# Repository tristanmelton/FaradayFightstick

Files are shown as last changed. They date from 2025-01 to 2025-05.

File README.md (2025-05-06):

### FaradayFightstick
Utilize Hall Effect sensors in an open-source leverless.

Use an ATMEGA microcontroller to read the analog out from the hall effect sensor located on the opposite side of the PCB from the switch. Then, the ATMEGA will act as the switch and output high or low to a Brooks board for each button press.

There are board versions for a RP2040, Brooks P5 Mini and Brooks Gen-5X Mini. I have tested the RP2040 and P5 Mini versions and they both work on PC.
## Setup
The board is relatively simple to set up - the most difficult part was soldering the USB-C for the ATMEGA32u4. I have no reflow oven so I used my conventional oven with solder paste, which works but is a little difficult to get the timing right to not melt the plastic in the connector.

Once all components are soldered, burn the Arduino bootloader with the "Arduino as ISP" option with an Arduino Uno or equivalent, or another bootloader burner, connected to the ICSP headers on the ATMEGA32u4 which are broken out for convenience, set to an Arduino Micro as the target. Then, plug in the USB-C and upload the ADC.ino sketch.

Once uploaded, unplug and hold LP while plugging back in and run the configurator python script (to be wrapped into an exe later). It should automatically detect the controller. If not, select the COM port corresponding to your board (should say COMXX: Arduino Micro), and click Connect. The progress bar will fill as the default values are read from memory. Set the values using the sliders and click "Submit New Thresholds". Wait for the progress bar to fill and then you can unplug.

Unplug from the ATMEGA side and plug the controller into your computer. If using the RP2040 board, upload the GP2040-CE firmware. Once done, you should be good to go!

There is compatibility for a MagicBoots with the RP2040 board but I have not tested it nor the P5 mini or Gen-5X versions as I don't own a PS5. Always open to donations :)
## TODO
- [ ] Test the P5 Mini version on a PS5.
- [x] Add an "unpressed" level so users have an idea of what range of value to put in
- [x] Add a diode on the voltage input from each USB socket to prevent backflow of current to the host PC and damaging it

## Changelog
# v1.1 (5/5/2025)
- Added boards for P5 mini and Gen-5X mini
- Added current-blocking diodes to prevent blowing up your USB if plugged into both USB ports at the same time
- Updated ADC firmware to support additional commands:
  - GETALLVAL;: get all current button values.
  - GETALLTRIG;: get all trigger threshold levels.
  - GETTRIG;XX: get a singular trigger threshold from memory.  XX indicates the memory offset to read from.
  - LP;X, MP;X, HP;X, SHP;X,...: Sets the trigger threshold value to X in absolute units.
- Updated interface software to use sliders from 100 to 0 to set the sensitivity. 100 is max sensitivity, 0 is no sensitivity.
- Software will try and auto-detect the controller when plugged in. 
# v1.0 (3/6/2025)
The leverless is working! I wrote a quick interface with Python to read and write button trigger thresholds to the EEPROM. The system works as an official "1.0"!

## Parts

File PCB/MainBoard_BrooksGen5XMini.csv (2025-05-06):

Reference | Value | Datasheet | Footprint | Qty | DNP
C1,C3,C4,C5,C6,C9,C19,C33 | 0.1u | ~ | Capacitor_SMD:C_0603_1608Metric | 8
C2,C11,C12,C20,C34 | 1u | ~ | Capacitor_SMD:C_0603_1608Metric | 5
C7 | 4.7u | ~ | Capacitor_SMD:C_0603_1608Metric | 1
C8,C10 | 22p | ~ | Capacitor_SMD:C_0603_1608Metric | 2
C14,C15,C16,C17,C18,C24,C25,C26,C30,C31,C32,C37,C38,C39,C40,C41 | 1n | ~ | Capacitor_SMD:C_0603_1608Metric | 16
D1 | LED_GREEN | ~ | LED_SMD:LED_0201_0603Metric | 1
D2 | LED_RED | ~ | LED_SMD:LED_0201_0603Metric | 1
D3,D4,D5,D6 | D | ~ |  | 4
J1,J3 | USB4105-GF-A |  | USB4105_GF_A:GCT_USB4105-GF-A | 2
J2 | Conn_01x06_Pin | ~ | Connector_PinHeader_2.54mm:PinHeader_2x03_P2.54mm_Vertical | 1
R1,R9,R10,R15 | 5.1k | ~ | Resistor_SMD:R_0603_1608Metric | 4
R2,R3,R8,R11,R12,R13,R14,R18,R19,R20,R24,R25,R26,R29,R30,R31,R32,R33 | 22 | ~ | Resistor_SMD:R_0603_1608Metric | 18
R4,R5 | 1k | ~ | Resistor_SMD:R_0603_1608Metric | 2
R6,R7 | 10k | ~ | Resistor_SMD:R_0603_1608Metric | 2
R27,R34 | 51 | ~ | Resistor_SMD:R_0603_1608Metric | 2
SW_RESET1 | SW_Push | ~ | Button_Switch_SMD:SW_SPST_TL3342 | 1
U1,U3 | ADC108S022CIMTX/NOPB | ADC108S022CIMTX/NOPB | ADCs:MTC16 | 2
U2,U21,U22,U23,U24,U25,U26,U27,U28,U29,U30,U31,U32,U33,U34,U35,U36,U37 | ~ |  | -- mixed values -- | 18
U4,U5,U6,U7,U8,U9,U10,U11,U12,U13,U14,U15,U16,U17,U18,U19 | DRV5053VAQDBZR | DRV5053VAQDBZR | HallEffect:DBZ0003A_N | 16
U20 | ATmega32U4-A | http://ww1.microchip.com/downloads/en/DeviceDoc/Atmel-7766-8-bit-AVR-ATmega16U4-32U4_Datasheet.pdf | Package_QFP:TQFP-44_10x10mm_P0.8mm | 1
Y2 | Crystal_GND24 | ~ | Crystal:Crystal_SMD_SeikoEpson_FA238-4Pin_3.2x2.5mm | 1

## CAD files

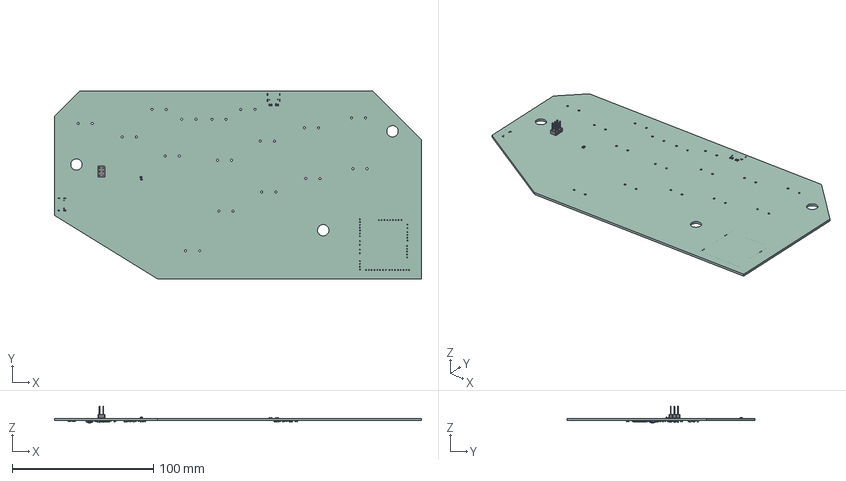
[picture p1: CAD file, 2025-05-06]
PCB/MainBoard_BrooksP5Mini.step
259.5 x 133.0 x 11.8 mm
PinHeader_2x03_P254mm_Vertical
D_0603 x 4
R_0603_1608Metric x 27
C_0603_1608Metric x 32
TQFP_44_10x10mm_P08mm
SW_SPST_TL3342
Crystal_SMD_SeikoEpson_FA238-4Pin_3.2x2.5mm
LED_0201_0603Metric
MainBoard_BrooksP5Mini_PCB

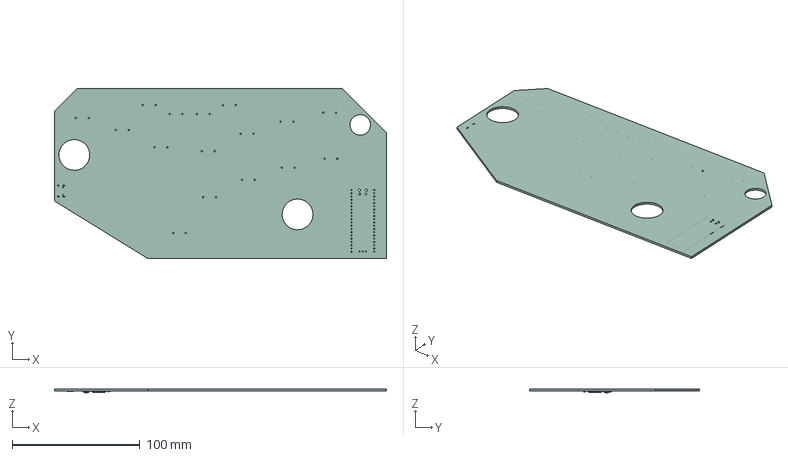
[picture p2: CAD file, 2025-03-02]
PCB/MainBoard_RP2040.step
259.5 x 133.0 x 3.19 mm
TQFP_44_10x10mm_P08mm
C_0603_1608Metric x 8
R_0603_1608Metric x 7
SW_SPST_TL3342
Crystal_SMD_SeikoEpson_FA238-4Pin_3.2x2.5mm
LED_0201_0603Metric
_autosave-MainBoard_RP2040_PCB

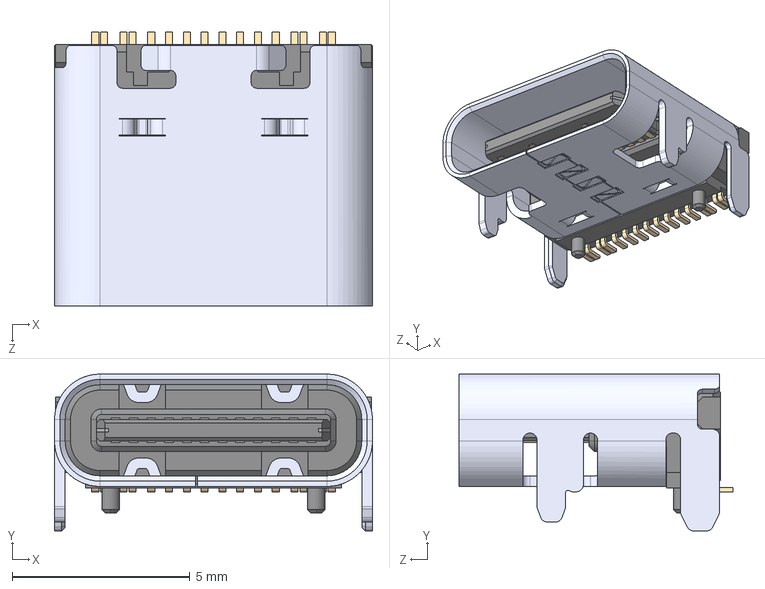
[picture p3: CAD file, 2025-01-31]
Components/USB4105_GF_A/USB4105-GF-A.step
8.94 x 4.41 x 7.71 mm

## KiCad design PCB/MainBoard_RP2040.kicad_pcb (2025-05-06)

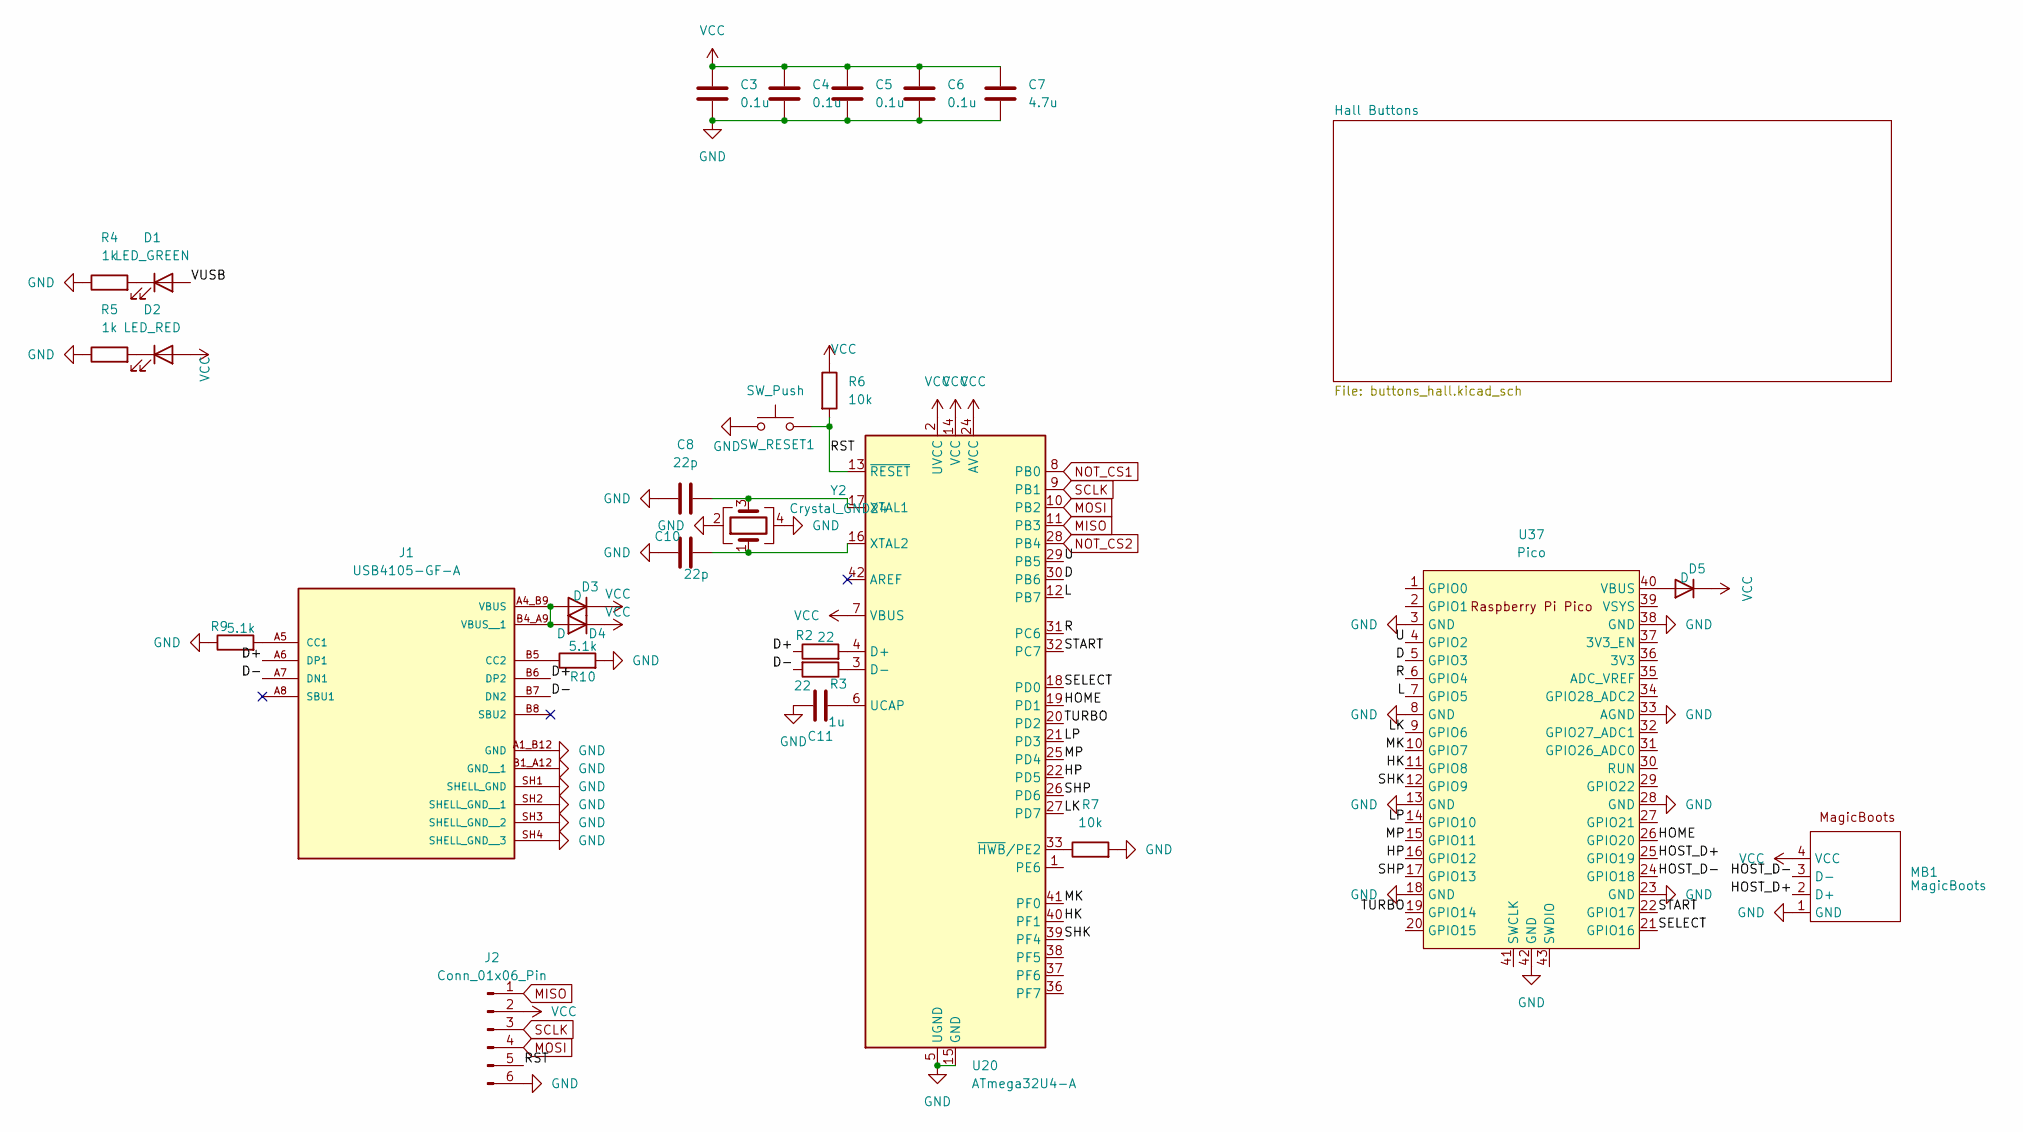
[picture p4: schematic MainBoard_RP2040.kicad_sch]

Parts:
C3, C4, C5, C6: 0.1u; C_0603_1608Metric
C7: 4.7u; C_0603_1608Metric
C8, C10: 22p; C_0603_1608Metric
C11: 1u; C_0603_1608Metric
D1: LED_GREEN; LED_0201_0603Metric
D2: LED_RED; LED_0201_0603Metric
D3, D4, D5: D; D_0603_1608Metric
J1: USB4105-GF-A; GCT_USB4105-GF-A; PARTREV B4
J2: Conn_01x06_Pin; PinHeader_2x03_P2.54mm_Vertical
MB1: MagicBoots
R2, R3: 22; R_0603_1608Metric
R4, R5: 1k; R_0603_1608Metric
R6, R7: 10k; R_0603_1608Metric
R9, R10: 5.1k; R_0603_1608Metric
SW_RESET1: SW_Push; SW_SPST_TL3342
U20: ATmega32U4-A; TQFP-44_10x10mm_P0.8mm
U37: Pico; RPi_Pico_SMD_TH
Y2: Crystal_GND24; Crystal_SMD_SeikoEpson_FA238-4Pin_3.2x2.5mm

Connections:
/D: U20.30 (PB6), U37.5 (GPIO3)
/D+: J1.A6 (DP1), J1.B6 (DP2), R2.1
/D-: J1.A7 (DN1), J1.B7 (DN2), R3.2
/HK: U20.40 (PF1), U37.11 (GPIO8)
/HOME: U20.19 (PD1), U37.26 (GPIO20)
/HOST_D+: MB1.2 (D+), U37.25 (GPIO19)
/HOST_D-: MB1.3 (D-), U37.24 (GPIO18)
/HP: U20.22 (PD5), U37.16 (GPIO12)
/L: U20.12 (PB7), U37.7 (GPIO5)
/LK: U20.27 (PD7), U37.9 (GPIO6)
/LP: U20.21 (PD3), U37.14 (GPIO10)
/MK: U20.41 (PF0), U37.10 (GPIO7)
/MP: U20.25 (PD4), U37.15 (GPIO11)
/R: U20.31 (PC6), U37.6 (GPIO4)
/RST: J2.5, R6.2, SW_RESET1.2, U20.13 (~RESET)
/SELECT: U20.18 (PD0), U37.21 (GPIO16)
/SHK: U20.39 (PF4), U37.12 (GPIO9)
/SHP: U20.26 (PD6), U37.17 (GPIO13)
/START: U20.32 (PC7), U37.22 (GPIO17)
/TURBO: U20.20 (PD2), U37.19 (GPIO14)
/U: U20.29 (PB5), U37.4 (GPIO2)
GND: C3.2, C4.2, C5.2, C6.2, C7.2, C8.1, C10.1, C11.1, J1.A1_B12 (GND), J1.B1_A12 (GND__1), J1.SH1 (SHELL_GND), J1.SH2 (SHELL_GND__1), J1.SH3 (SHELL_GND__2), J1.SH4 (SHELL_GND__3), J2.6, MB1.1 (GND), R4.1, R5.1, R7.2, R9.1, R10.2, SW_RESET1.1, U20.5 (UGND), U20.15 (GND), U20.23 (GND), U20.35 (GND), U20.43 (GND), U37.3 (GND), U37.8 (GND), U37.13 (GND), U37.18 (GND), U37.23 (GND), U37.28 (GND), U37.33 (AGND), U37.38 (GND), U37.42 (GND), Y2.2, Y2.4; also elsewhere on the board
MISO: J2.1, U20.11 (PB3); also elsewhere on the board
MOSI: J2.4, U20.10 (PB2); also elsewhere on the board
NOT_CS1: U20.8 (PB0); also elsewhere on the board
NOT_CS2: U20.28 (PB4); also elsewhere on the board
unnamed: D1.1 (K), R4.2
unnamed: D2.1 (K), R5.2
unnamed: D3.2 (A), D4.2 (A), J1.A4_B9 (VBUS), J1.B4_A9 (VBUS__1)
unnamed: D5.2 (A), U37.40 (VBUS)
unnamed: J1.A5 (CC1), R9.2
unnamed: J1.B5 (CC2), R10.1
unnamed: R2.2, U20.4 (D+)
unnamed: R3.1, U20.3 (D-)
unnamed: C11.2, U20.6 (UCAP)
unnamed: C8.2, U20.17 (XTAL1), Y2.3
unnamed: C10.2, U20.16 (XTAL2), Y2.1
unnamed: R7.1, U20.33 (~HWB/PE2)
SCLK: J2.3, U20.9 (PB1); also elsewhere on the board
VCC: C3.1, C4.1, C5.1, C6.1, C7.1, D2.2 (A), D3.1 (K), D4.1 (K), D5.1 (K), J2.2, MB1.4 (VCC), R6.1, U20.2 (UVCC), U20.7 (VBUS), U20.14 (VCC), U20.24 (AVCC), U20.34 (VCC), U20.44 (AVCC); also elsewhere on the board

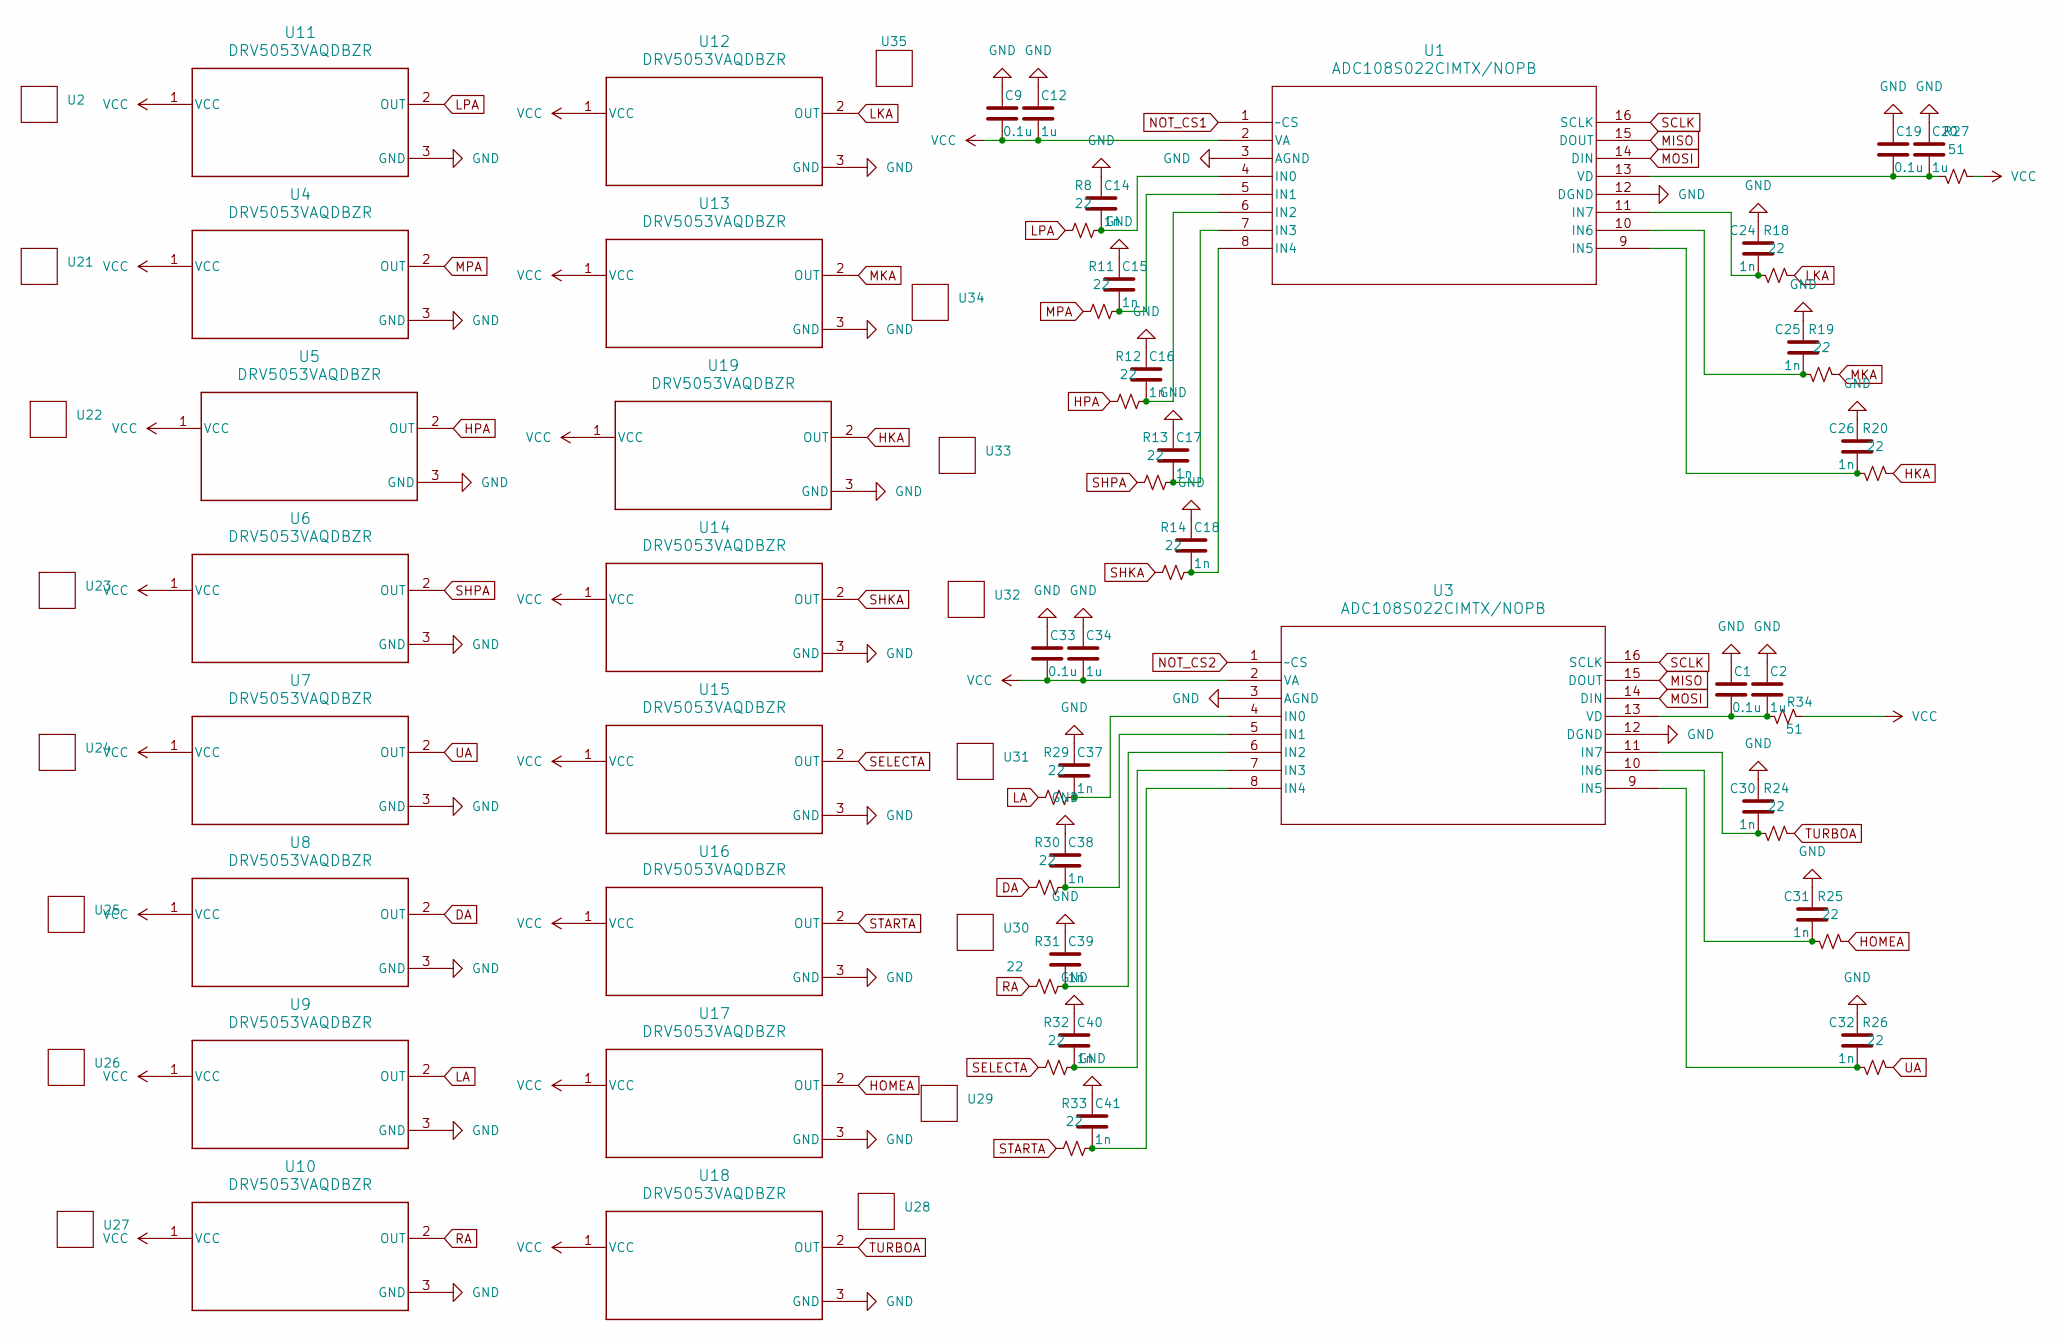
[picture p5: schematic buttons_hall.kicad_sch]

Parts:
C1, C9, C19, C33: 0.1u; C_0603_1608Metric
C2, C12, C20, C34: 1u; C_0603_1608Metric
C14, C15, C16, C17, C18, C24, C25, C26, C30, C31, C32, C37, C38, C39, C40, C41: 1n; C_0603_1608Metric
R8, R11, R12, R13, R14, R18, R19, R20, R24, R25, R26, R29, R30, R31, R32, R33: 22; R_0603_1608Metric
R27, R34: 51; R_0603_1608Metric
U1, U3: ADC108S022CIMTX/NOPB; MTC16
U2, U21, U22, U23, U24, U25, U26, U27, U28, U29, U30, U31, U32, U33, U34, U35: Gateron Jade Pro Magnetic
U4, U5, U6, U7, U8, U9, U10, U11, U12, U13, U14, U15, U16, U17, U18, U19: DRV5053VAQDBZR; DBZ0003A_N

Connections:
DA: R30.1, U8.2 (OUT)
GND: C1.1, C2.1, C9.1, C12.1, C14.1, C15.1, C16.1, C17.1, C18.1, C19.1, C20.1, C24.1, C25.1, C26.1, C30.1, C31.1, C32.1, C33.1, C34.1, C37.1, C38.1, C39.1, C40.1, C41.1, U1.3 (AGND), U1.12 (DGND), U3.3 (AGND), U3.12 (DGND), U4.3 (GND), U5.3 (GND), U6.3 (GND), U7.3 (GND), U8.3 (GND), U9.3 (GND), U10.3 (GND), U11.3 (GND), U12.3 (GND), U13.3 (GND), U14.3 (GND), U15.3 (GND), U16.3 (GND), U17.3 (GND), U18.3 (GND), U19.3 (GND); also elsewhere on the board
HKA: R20.1, U19.2 (OUT)
HOMEA: R25.1, U17.2 (OUT)
HPA: R12.1, U5.2 (OUT)
LA: R29.1, U9.2 (OUT)
LKA: R18.1, U12.2 (OUT)
LPA: R8.1, U11.2 (OUT)
MISO: U1.15 (DOUT), U3.15 (DOUT); also elsewhere on the board
MKA: R19.1, U13.2 (OUT)
MOSI: U1.14 (DIN), U3.14 (DIN); also elsewhere on the board
MPA: R11.1, U4.2 (OUT)
NOT_CS1: U1.1 (~CS); also elsewhere on the board
NOT_CS2: U3.1 (~CS); also elsewhere on the board
unnamed: C14.2, R8.2, U1.4 (IN0)
unnamed: C15.2, R11.2, U1.5 (IN1)
unnamed: C16.2, R12.2, U1.6 (IN2)
unnamed: C17.2, R13.2, U1.7 (IN3)
unnamed: C18.2, R14.2, U1.8 (IN4)
unnamed: C26.2, R20.2, U1.9 (IN5)
unnamed: C25.2, R19.2, U1.10 (IN6)
unnamed: C24.2, R18.2, U1.11 (IN7)
unnamed: C19.2, C20.2, R27.2, U1.13 (VD)
unnamed: C37.2, R29.2, U3.4 (IN0)
unnamed: C38.2, R30.2, U3.5 (IN1)
unnamed: C39.2, R31.2, U3.6 (IN2)
unnamed: C40.2, R32.2, U3.7 (IN3)
unnamed: C41.2, R33.2, U3.8 (IN4)
unnamed: C32.2, R26.2, U3.9 (IN5)
unnamed: C31.2, R25.2, U3.10 (IN6)
unnamed: C30.2, R24.2, U3.11 (IN7)
unnamed: C1.2, C2.2, R34.2, U3.13 (VD)
RA: R31.1, U10.2 (OUT)
SCLK: U1.16 (SCLK), U3.16 (SCLK); also elsewhere on the board
SELECTA: R32.1, U15.2 (OUT)
SHKA: R14.1, U14.2 (OUT)
SHPA: R13.1, U6.2 (OUT)
STARTA: R33.1, U16.2 (OUT)
TURBOA: R24.1, U18.2 (OUT)
UA: R26.1, U7.2 (OUT)
VCC: C9.2, C12.2, C33.2, C34.2, R27.1, R34.1, U1.2 (VA), U3.2 (VA), U4.1 (VCC), U5.1 (VCC), U6.1 (VCC), U7.1 (VCC), U8.1 (VCC), U9.1 (VCC), U10.1 (VCC), U11.1 (VCC), U12.1 (VCC), U13.1 (VCC), U14.1 (VCC), U15.1 (VCC), U16.1 (VCC), U17.1 (VCC), U18.1 (VCC), U19.1 (VCC); also elsewhere on the board

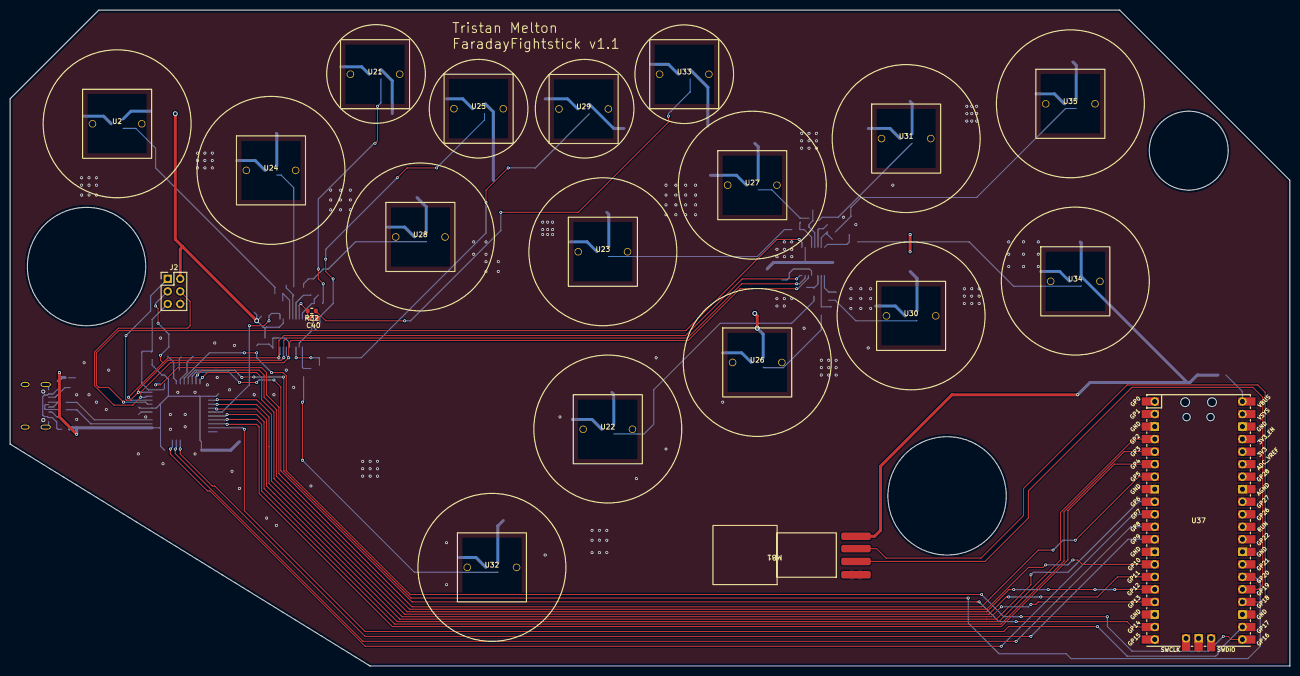
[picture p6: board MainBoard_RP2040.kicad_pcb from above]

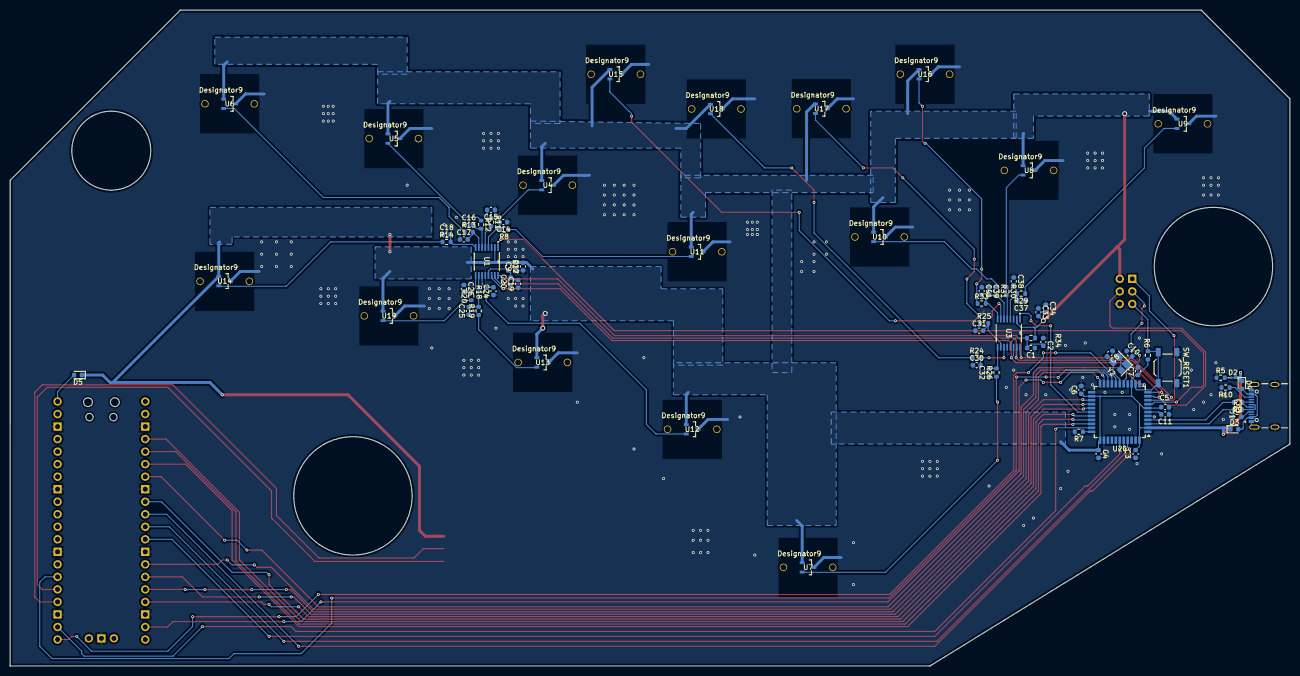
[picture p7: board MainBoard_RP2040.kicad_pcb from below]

Board: 2 copper layers, 259.5 x 133.0 mm, 102 parts (81 on the bottom side), 73 nets.

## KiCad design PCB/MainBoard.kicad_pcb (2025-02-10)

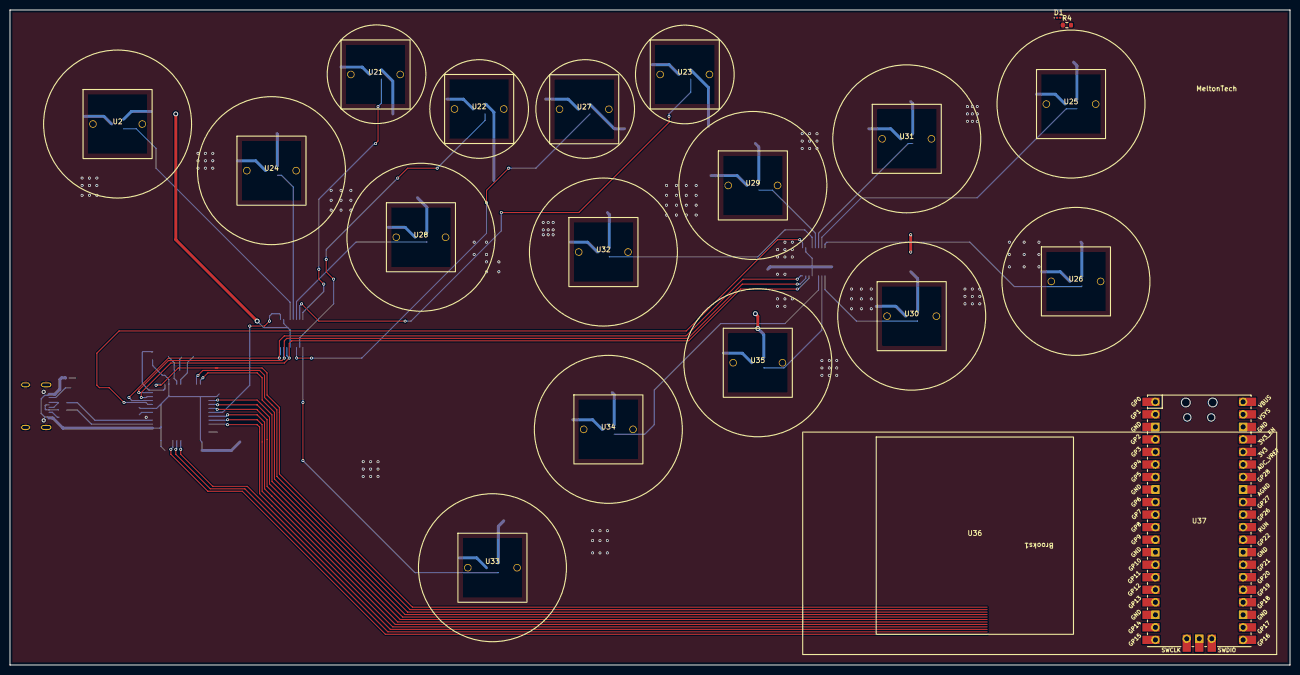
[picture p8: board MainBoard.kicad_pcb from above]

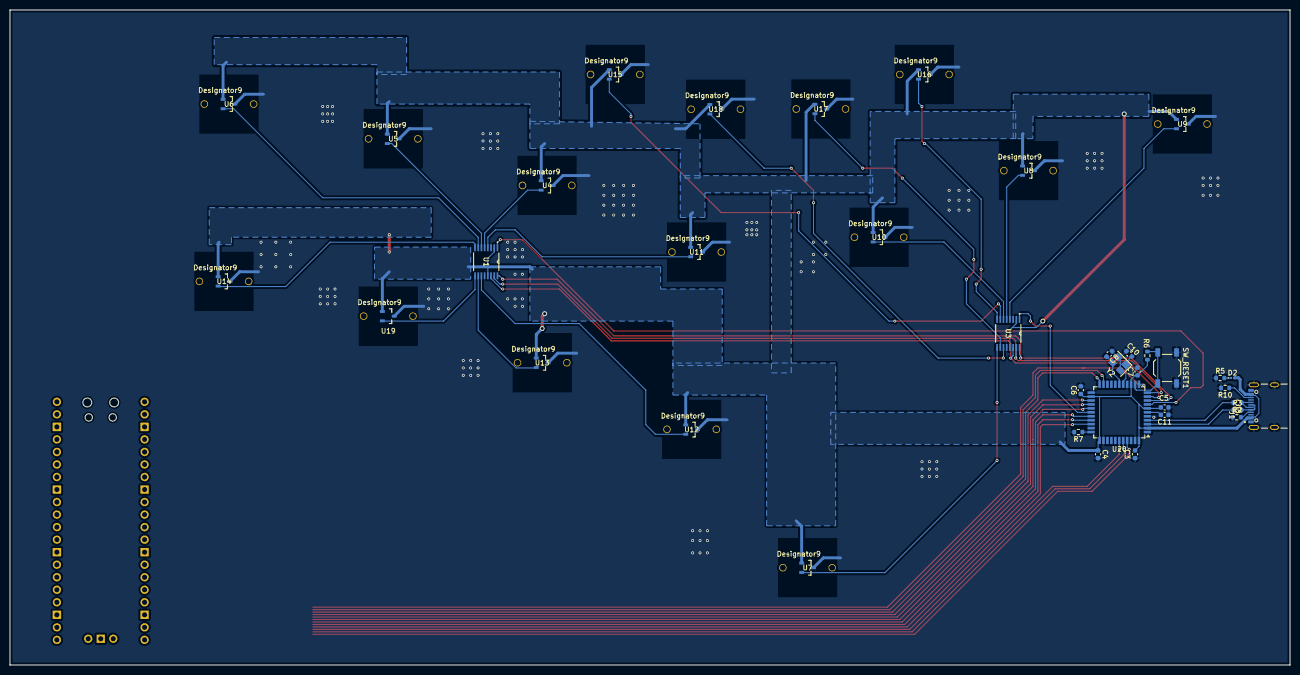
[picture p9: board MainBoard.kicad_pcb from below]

Board: 2 copper layers, 259.5 x 132.8 mm, 59 parts (38 on the bottom side), 36 nets.

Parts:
Brooks1: BrooksP5Plus
C3, C4, C5, C6: 0.1u; C_0603_1608Metric
C7: 4.7u; C_0603_1608Metric
C8, C10: 22p; C_0603_1608Metric
C11: 1u; C_0603_1608Metric
D1: LED_GREEN; LED_0201_0603Metric
D2: LED_RED; LED_0201_0603Metric
J1: USB4105-GF-A; GCT_USB4105-GF-A
R2, R3: 22; R_0603_1608Metric
R4, R5: 1k; R_0603_1608Metric
R6, R7: 10k; R_0603_1608Metric
R9, R10: 5.1k; R_0603_1608Metric
SW_RESET1: SW_Push; SW_SPST_TL3342
U1, U3: ADC108S022CIMTX/NOPB; MTC16
U2, U21, U22, U23, U24, U25, U26, U27, U28, U29, U30, U31, U32, U33, U34, U35: Gateron Jade Pro Magnetic
U4, U5, U6, U7, U8, U9, U10, U11, U12, U13, U14, U15, U16, U17, U18, U19: DRV5053VAQDBZR; DBZ0003A_N
U20: ATmega32U4-A; TQFP-44_10x10mm_P0.8mm
U36: BrooksP5Mini
U37: Pico; RPi_Pico_SMD_TH
Y2: Crystal_GND24; Crystal_SMD_SeikoEpson_FA238-4Pin_3.2x2.5mm

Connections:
/D+: J1.A6 (DP1), J1.B6 (DP2), R2.1
/D-: J1.A7 (DN1), J1.B7 (DN2), R3.2
DA: U3.5 (IN1), U8.2 (OUT)
GND: C3.2, C4.2, C5.2, C6.2, C7.2, C8.1, C10.1, C11.1, J1.A1_B12 (GND), J1.B1_A12 (GND__1), J1.SH1 (SHELL_GND), J1.SH2 (SHELL_GND__1), J1.SH3 (SHELL_GND__2), J1.SH4 (SHELL_GND__3), R4.1, R5.1, R7.2, R9.1, R10.2, SW_RESET1.1, U1.3 (AGND), U1.12 (DGND), U3.3 (AGND), U3.12 (DGND), U4.3 (GND), U5.3 (GND), U6.3 (GND), U7.3 (GND), U8.3 (GND), U9.3 (GND), U10.3 (GND), U11.3 (GND), U12.3 (GND), U13.3 (GND), U14.3 (GND), U15.3 (GND), U16.3 (GND), U17.3 (GND), U18.3 (GND), U19.3 (GND), U20.5 (UGND), U20.15 (GND), U20.23 (GND), U20.35 (GND), U20.43 (GND), Y2.2, Y2.4
HKA: U1.9 (IN5), U19.2 (OUT)
HOMEA: U3.10 (IN6), U17.2 (OUT)
HPA: U1.6 (IN2), U5.2 (OUT)
LA: U3.4 (IN0), U9.2 (OUT)
LKA: U1.11 (IN7), U12.2 (OUT)
LPA: U1.4 (IN0), U11.2 (OUT)
MISO: U1.15 (DOUT), U3.15 (DOUT), U20.11 (PB3)
MKA: U1.10 (IN6), U13.2 (OUT)
MOSI: U1.14 (DIN), U3.14 (DIN), U20.10 (PB2)
MPA: U1.5 (IN1), U4.2 (OUT)
NOT_CS1: U1.1 (~CS), U20.8 (PB0)
NOT_CS2: U3.1 (~CS), U20.28 (PB4)
unnamed: D1.1 (K), R4.2
unnamed: D2.1 (K), R5.2
unnamed: J1.A5 (CC1), R9.2
unnamed: J1.B5 (CC2), R10.1
unnamed: R2.2, U20.4 (D+)
unnamed: R3.1, U20.3 (D-)
unnamed: C11.2, U20.6 (UCAP)
unnamed: C8.2, U20.17 (XTAL1), Y2.3
unnamed: C10.2, U20.16 (XTAL2), Y2.1
unnamed: R7.1, U20.33 (~HWB/PE2)
unnamed: R6.2, SW_RESET1.2, U20.13 (~RESET)
RA: U3.6 (IN2), U10.2 (OUT)
SCLK: U1.16 (SCLK), U3.16 (SCLK), U20.9 (PB1)
SELECTA: U3.7 (IN3), U15.2 (OUT)
SHKA: U1.8 (IN4), U14.2 (OUT)
SHPA: U1.7 (IN3), U6.2 (OUT)
STARTA: U3.8 (IN4), U16.2 (OUT)
TURBOA: U3.11 (IN7), U18.2 (OUT)
UA: U3.9 (IN5), U7.2 (OUT)
VCC: C3.1, C4.1, C5.1, C6.1, C7.1, D2.2 (A), J1.A4_B9 (VBUS), J1.B4_A9 (VBUS__1), R6.1, U1.2 (VA), U1.13 (VD), U3.2 (VA), U3.13 (VD), U4.1 (VCC), U5.1 (VCC), U6.1 (VCC), U7.1 (VCC), U8.1 (VCC), U9.1 (VCC), U10.1 (VCC), U11.1 (VCC), U12.1 (VCC), U13.1 (VCC), U14.1 (VCC), U15.1 (VCC), U16.1 (VCC), U17.1 (VCC), U18.1 (VCC), U19.1 (VCC), U20.2 (UVCC), U20.7 (VBUS), U20.14 (VCC), U20.24 (AVCC), U20.34 (VCC), U20.44 (AVCC)

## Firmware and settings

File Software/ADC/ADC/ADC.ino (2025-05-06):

#include <SPI.h>
#include <limits.h>
#include <EEPROM.h>

// SPI Pins
#define MISO 11
#define MOSI 10
#define SCLK 9

#define CS1 17
#define CS2 8

#define LP 1
#define MP 4
#define HP 30
#define SHP 12
#define LK 6
#define MK 23
#define HK 22
#define SHK 21


#define LEFT 11
#define DOWN 10
#define RIGHT 5
#define SELECT 3
#define UP 9
#define HOME 2 
#define TURBO 0
#define START 13


// Registry Values
#define CH0 0b00000000
#define CH1 0b00001000
#define CH2 0b00010000
#define CH3 0b00011000
#define CH4 0b00100000
#define CH5 0b00101000
#define CH6 0b00110000
#define CH7 0b00111000

float lp_val = 0;
float lp_thres;
float mp_val = 0;
float mp_thres = 300;
float hp_val = 0;
float hp_thres = 300;
float shp_val = 0;
float shp_thres = 300;

float shk_val = 0;
float shk_thres = 300;
float hk_val = 0;
float hk_thres = 300;
float mk_val = 0;
float mk_thres = 300;
float lk_val = 0;
float lk_thres = 300;

float left_val = 0;
float left_thres = 300;
float right_val = 0;
float right_thres = 300;
float down_val = 0;
float down_thres = 300;
float up_val = 0;
float up_thres = 300;
float sel_val = 0;
float sel_thres = 300;
float sta_val = 0;
float sta_thres = 300;
float home_val = 0;
float home_thres = 300;
float turbo_val = 0;
float turbo_thres = 300;

bool configMode = false;

template<typename T>
void printBinary(T value)
{
    for ( size_t mask = 1 << ((sizeof(value) * CHAR_BIT) - 1); mask; mask >>= 1 )
    {
        Serial.print(value & mask ? "1" : "0");
    }
}


void ReadThresholds() 
{
  EEPROM.get(0, lp_thres);
  EEPROM.get(4, mp_thres);
  EEPROM.get(8, hp_thres);
  EEPROM.get(12, shp_thres);
  EEPROM.get(16, lk_thres);
  EEPROM.get(20, mk_thres);
  EEPROM.get(24, hk_thres);
  EEPROM.get(28, shk_thres);
  EEPROM.get(32, left_thres);
  EEPROM.get(36, right_thres);
  EEPROM.get(40, up_thres);
  EEPROM.get(44, down_thres);
  EEPROM.get(48, sta_thres);
  EEPROM.get(52, sel_thres);
  EEPROM.get(56, home_thres);
  EEPROM.get(60, turbo_thres);
}
void setup()
{
  Serial.begin(57600);
  SPI.begin();
  SPI.beginTransaction(SPISettings(100, MSBFIRST, SPI_MODE3));
  pinMode(MOSI, OUTPUT);
  pinMode(MISO, INPUT);
  pinMode(SCLK, OUTPUT);
  pinMode(CS1, OUTPUT);
  pinMode(CS2, OUTPUT);

  pinMode(LP, OUTPUT);
  pinMode(MP, OUTPUT);
  pinMode(HP, OUTPUT);
  pinMode(SHP, OUTPUT);
  pinMode(LK, OUTPUT);
  pinMode(MK, OUTPUT);
  pinMode(HK, OUTPUT);
  pinMode(SHK,OUTPUT);

  pinMode(LEFT, OUTPUT);
  pinMode(RIGHT, OUTPUT);
  pinMode(UP, OUTPUT);
  pinMode(DOWN, OUTPUT);
  pinMode(START, OUTPUT);
  pinMode(SELECT, OUTPUT);
  pinMode(HOME, OUTPUT);
  pinMode(TURBO, OUTPUT);

  digitalWrite(LP, HIGH);
  digitalWrite(MP, HIGH);
  digitalWrite(HP, HIGH);
  digitalWrite(SHP, HIGH);
  digitalWrite(LK, HIGH);
  digitalWrite(MK, HIGH);
  digitalWrite(HK, HIGH);
  digitalWrite(SHK, HIGH);

  digitalWrite(LEFT, HIGH);
  digitalWrite(RIGHT, HIGH);
  digitalWrite(DOWN, HIGH);
  digitalWrite(UP, HIGH);
  digitalWrite(SELECT, HIGH);
  digitalWrite(START, HIGH);
  digitalWrite(HOME, HIGH);
  digitalWrite(TURBO, HIGH);

  digitalWrite(CS1, HIGH); //disable at start
  digitalWrite(CS2, HIGH); //disable at start

  ReadThresholds();

  lp_val = readAnalogInput(CS1, CH1);
  if(lp_val < 200) { // If we are going into config mode
    configMode = true;
    Serial.println("Entering Config Mode");
  }
}

void loop()
{
  if(configMode) {
    while (Serial.available() == 0) {}     //wait for data available
    String test = Serial.readString();

    const char* cstr = test.c_str();
    char* token = strtok(cstr, ";");
    char* button = token;
    token= strtok(0, ";");
    float val = atoi(token);

    if(!strcmp(button, "GETALLVAL")) {
      lp_val = readAnalogInput(CS1, CH1);
      mp_val = readAnalogInput(CS1, CH2);
      hp_val = readAnalogInput(CS1, CH3);
      shp_val = readAnalogInput(CS1, CH4);
      shk_val = readAnalogInput(CS1, CH5);
      hk_val = readAnalogInput(CS1, CH6);
      mk_val = readAnalogInput(CS1, CH7);
      lk_val = readAnalogInput(CS1, CH0);

      left_val = readAnalogInput(CS2, CH1);
      down_val = readAnalogInput(CS2, CH2);
      right_val = readAnalogInput(CS2, CH3);
      sel_val = readAnalogInput(CS2, CH4);
      sta_val = readAnalogInput(CS2, CH5);
      up_val = readAnalogInput(CS2, CH6);
      home_val = readAnalogInput(CS2, CH7);
      turbo_val = readAnalogInput(CS2, CH0);
      Serial.print(lp_val);
      Serial.print(';');
      Serial.print(mp_val);
      Serial.print(';');
      Serial.print(hp_val);
      Serial.print(';');
      Serial.print(shp_val);
      Serial.print(';');
      Serial.print(lk_val);
      Serial.print(';');
      Serial.print(mk_val);
      Serial.print(';');
      Serial.print(hk_val);
      Serial.print(';');
      Serial.print(shk_val);
      Serial.print(';');
      Serial.print(left_val);
      Serial.print(';');
      Serial.print(down_val);
      Serial.print(';');
      Serial.print(right_val);
      Serial.print(';');
      Serial.print(up_val);
      Serial.print(';');
      Serial.print(sel_val);
      Serial.print(';');
      Serial.print(sta_val);
      Serial.print(';');
      Serial.print(home_val);
      Serial.print(';');
      Serial.println(turbo_val);
    }
    if(!strcmp(button, "GETALLTRIG")) {
      Serial.print(lp_thres);
      Serial.print(';');
      Serial.print(mp_thres);
      Serial.print(';');
      Serial.print(hp_thres);
      Serial.print(';');
      Serial.print(shp_thres);
      Serial.print(';');
      Serial.print(lk_thres);
      Serial.print(';');
      Serial.print(mk_thres);
      Serial.print(';');
      Serial.print(hk_thres);
      Serial.print(';');
      Serial.print(shk_thres);
      Serial.print(';');
      Serial.print(left_thres);
      Serial.print(';');
      Serial.print(down_thres);
      Serial.print(';');
      Serial.print(right_thres);
      Serial.print(';');
      Serial.print(up_thres);
      Serial.print(';');
      Serial.print(sel_thres);
      Serial.print(';');
      Serial.print(sta_thres);
      Serial.print(';');
      Serial.print(home_thres);
      Serial.print(';');
      Serial.println(turbo_thres);
    }
    if(!strcmp(button,"GETTRIG")) {
      //Serial.print("Getting memory value... "); Serial.println(int(val));
      float memval;
      EEPROM.get((int)val, memval);
      Serial.println(memval);
    }
    else if(!strcmp(button,"LP")) {
      //Serial.print("Writing "); Serial.print(val); Serial.print(" to "); Serial.println(button);
      lp_thres=val;
      EEPROM.put(0, val);
    }
    else if(!strcmp(button,"MP")) {
      //Serial.print("Writing "); Serial.print(val); Serial.print(" to "); Serial.println(button);
      mp_thres=val;
      EEPROM.put(4, val);
    }
    else if(!strcmp(button,"HP")) {
      hp_thres=val;
      //Serial.print("Writing "); Serial.print(val); Serial.print(" to "); Serial.println(button);
      EEPROM.put(8, val);
    }
    else if(!strcmp(button,"SHP")) {
      shp_thres=val;
      //Serial.print("Writing "); Serial.print(val); Serial.print(" to "); Serial.println(button);
      EEPROM.put(12, val);
    }
    else if(!strcmp(button,"LK")) {
      lk_thres=val;
      //Serial.print("Writing "); Serial.print(val); Serial.print(" to "); Serial.println(button);
      EEPROM.put(16, val);
    }
    else if(!strcmp(button,"MK")) {
      mk_thres=val;
      //Serial.print("Writing "); Serial.print(val); Serial.print(" to "); Serial.println(button);
      EEPROM.put(20, val);
    }
    else if(!strcmp(button,"HK")) {
      hk_thres=val;
      //Serial.print("Writing "); Serial.print(val); Serial.print(" to "); Serial.println(button);
      EEPROM.put(24, val);
    }
    else if(!strcmp(button,"SHK")) {
      shk_thres=val;
      //Serial.print("Writing "); Serial.print(val); Serial.print(" to "); Serial.println(button);
      EEPROM.put(28, val);
    }    
    else if(!strcmp(button,"LEFT")) {
      left_thres=val;
      //Serial.print("Writing "); Serial.print(val); Serial.print(" to "); Serial.println(button);
      EEPROM.put(32, val);
    }
    else if(!strcmp(button,"RIGHT")) {
      right_thres=val;
      //Serial.print("Writing "); Serial.print(val); Serial.print(" to "); Serial.println(button);
      EEPROM.put(36, val);
    }
    else if(!strcmp(button,"UP")) {
      up_thres=val;
      //Serial.print("Writing "); Serial.print(val); Serial.print(" to "); Serial.println(button);
      EEPROM.put(40, val);
    }
    else if(!strcmp(button,"DOWN")) {
      down_thres=val;
      //Serial.print("Writing "); Serial.print(val); Serial.print(" to "); Serial.println(button);
      EEPROM.put(44, val);
    } 
    else if(!strcmp(button,"START")) {
      sta_thres=val;
      //Serial.print("Writing "); Serial.print(val); Serial.print(" to "); Serial.println(button);
      EEPROM.put(48, val);
    }
    else if(!strcmp(button,"SELECT")) {
      sel_thres=val;
      //Serial.print("Writing "); Serial.print(val); Serial.print(" to "); Serial.println(button);
      EEPROM.put(52, val);
    }
    else if(!strcmp(button,"HOME")) {
      home_thres=val;
      //Serial.print("Writing "); Serial.print(val); Serial.print(" to "); Serial.println(button);
      EEPROM.put(56, val);
    }
    else if(!strcmp(button,"TURBO")) {
      turbo_thres=val;
      //Serial.print("Writing "); Serial.print(val); Serial.print(" to "); Serial.println(button);
      EEPROM.put(60, val);
    } 
    //Serial.println("Written");
  } 
  else
  {
    lp_val = readAnalogInput(CS1, CH1);
    mp_val = readAnalogInput(CS1, CH2);
    hp_val = readAnalogInput(CS1, CH3);
    shp_val = readAnalogInput(CS1, CH4);
    shk_val = readAnalogInput(CS1, CH5);
    hk_val = readAnalogInput(CS1, CH6);
    mk_val = readAnalogInput(CS1, CH7);
    lk_val = readAnalogInput(CS1, CH0);

    left_val = readAnalogInput(CS2, CH1);
    down_val = readAnalogInput(CS2, CH2);
    right_val = readAnalogInput(CS2, CH3);
    sel_val = readAnalogInput(CS2, CH4);
    sta_val = readAnalogInput(CS2, CH5);
    up_val = readAnalogInput(CS2, CH6);
    home_val = readAnalogInput(CS2, CH7);
    turbo_val = readAnalogInput(CS2, CH0);

    check_thresholds();
    bool ACTIONS_PRINT_DEBUG = false;
    bool DIRECTIONS_PRINT_DEBUG = false;
    if(ACTIONS_PRINT_DEBUG) {
      Serial.print("LP: ");
      Serial.print(lp_val);
      Serial.print(" MP: ");
      Serial.print(mp_val);
      Serial.print(" HP: ");
      Serial.print(hp_val);
      Serial.print(" SHP: ");
      Serial.print(shp_val);
      Serial.print(" LK: ");
      Serial.print(lk_val);
      Serial.print(" MK: ");
      Serial.print(mk_val);
      Serial.print(" HK: ");
      Serial.print(hk_val);
      Serial.print(" SHK: ");
      Serial.println(shk_val);
    }
    if(DIRECTIONS_PRINT_DEBUG) {
      Serial.print(" LEFT: ");
      Serial.print(left_val);
      Serial.print(" DOWN: ");
      Serial.print(down_val);
      Serial.print(" RIGHT: ");
      Serial.print(right_val);
      Serial.print(" SELECT: ");
      Serial.print(sel_val);
      Serial.print(" START: ");
      Serial.print(sta_val);
      Serial.print(" UP: ");
      Serial.print(up_val);
      Serial.print(" HOME: ");
      Serial.print(home_val);
      Serial.print(" TURBO: ");
      Serial.println(turbo_val);
    }
  } 

}

void check_thresholds()
{
  //Punches
  if(lp_val < lp_thres) {
    digitalWrite(LP, LOW);
    Serial.println("LP PRESSED");
  } else {
    digitalWrite(LP, HIGH);
  }
  if(mp_val < mp_thres) {
    digitalWrite(MP, LOW);
    Serial.println("MP PRESSED");
  } else {
    digitalWrite(
      MP, HIGH);
  }
  if(hp_val < hp_thres) {
    digitalWrite(HP, LOW);
    Serial.println("HP PRESSED");
  } else {
    digitalWrite(HP, HIGH);
  }
  if(shp_val < shp_thres) {
    digitalWrite(SHP, LOW);
    Serial.println("SHP PRESSED");
  } else {
    digitalWrite(SHP, HIGH);
  }    

  //Kicks
  if(lk_val < lk_thres) {
    digitalWrite(LK, LOW);
    Serial.println("LK PRESSED");
  } else {
    digitalWrite(LK, HIGH);
  }
  if(mk_val < mk_thres) {
    digitalWrite(MK, LOW);
    Serial.println("MK PRESSED");
  } else {
    digitalWrite(
      MK, HIGH);
  }
    if(hk_val < hk_thres) {
    digitalWrite(HK, LOW);
    Serial.println("HK PRESSED");
  } else {
    digitalWrite(HK, HIGH);
  }
  if(shk_val < shk_thres) {
    digitalWrite(SHK, LOW);
    Serial.println("SHK PRESSED");
  } else {
    digitalWrite(SHK, HIGH);
  }   

    //Directionals
  if(up_val < up_thres) {
    digitalWrite(UP, LOW);
    Serial.println("UP PRESSED");
  } else {
    digitalWrite(UP, HIGH);
  }
  if(down_val < down_thres) {
    digitalWrite(DOWN, LOW);
    Serial.println("DOWN PRESSED");
  } else {
    digitalWrite(DOWN, HIGH);
  }
  if(left_val < left_thres) {
    digitalWrite(LEFT, LOW);
    Serial.println("LEFT PRESSED");
  } else {
    digitalWrite(LEFT, HIGH);
  }
  if(right_val < right_thres) {
    digitalWrite(RIGHT, LOW);
    Serial.println("RIGHT PRESSED");
  } else {
    digitalWrite(RIGHT, HIGH);
  }    

  //Menu Buttons
  if(sta_val < sta_thres) {
    digitalWrite(START, LOW);
    Serial.println("START PRESSED");
  } else {
    digitalWrite(START, HIGH);
  }
  if(sel_val < sel_thres) {
    digitalWrite(SELECT, LOW);
    Serial.println("SELECT PRESSED");
  } else {
    digitalWrite(SELECT, HIGH);
  }
    if(home_val < home_thres) {
    digitalWrite(HOME, LOW);
    Serial.println("HOME PRESSED");
  } else {
    digitalWrite(HOME, HIGH);
  }
  if(turbo_val < turbo_thres) {
    digitalWrite(TURBO, LOW);
    Serial.println("TURBO PRESSED");
  } else {
    digitalWrite(TURBO, HIGH);
  }   
}
uint16_t readAnalogInput(int chipSelect, byte channel)
{
  digitalWrite(chipSelect, LOW);  
  byte msb = SPI.transfer(channel);
  byte lsb = SPI.transfer(0x00);
  digitalWrite(chipSelect, HIGH);
  uint16_t result = (msb << 8) | (lsb);
  return result;
}

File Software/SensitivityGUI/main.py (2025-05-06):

import serial
from serial import SerialException
from tkinter import * 
from tkinter import ttk
from time import sleep

import serial.tools.list_ports

import threading


ports = serial.tools.list_ports.comports()
serial_port = None

maxvals = []

root = Tk()
root.title("Faraday Fightstick Configurator")
frame_connect = Frame(root)
frame_buttonconfig = Frame(root)

frame_connect.grid()
#rame_buttonconfig.pack()

listbox_comports = Listbox(frame_connect,height = 10, width = 50)

progressbar_reading = ttk.Progressbar(frame_connect, orient=HORIZONTAL,length=160)
progressbar_writing = ttk.Progressbar(frame_buttonconfig, orient=HORIZONTAL,length=160)

label_connect = Label(frame_connect, text="Select a Serial Port")
label_buttonsettings = Label(frame_buttonconfig, text="Button Sensitivity Configuration")



label_lp = Label(frame_buttonconfig, text="LP").grid(row=1, column=0)
slider_lp = Scale(frame_buttonconfig, from_=100, to=0)
slider_lp.grid(row=1,column=1)
label_mp = Label(frame_buttonconfig, text="MP").grid(row=1, column=2)
slider_mp = Scale(frame_buttonconfig, from_=100, to=0)
slider_mp.grid(row=1,column=3)
label_hp = Label(frame_buttonconfig, text="HP").grid(row=1, column=4)
slider_hp = Scale(frame_buttonconfig, from_=100, to=0)
slider_hp.grid(row=1,column=5)
label_shp = Label(frame_buttonconfig, text="SHP").grid(row=1, column=6)
slider_shp = Scale(frame_buttonconfig, from_=100, to=0)
slider_shp.grid(row=1,column=7)

label_lk = Label(frame_buttonconfig, text="LK").grid(row=2, column=0)
slider_lk = Scale(frame_buttonconfig, from_=100, to=0)
slider_lk.grid(row=2,column=1)
label_mk = Label(frame_buttonconfig, text='MK').grid(row=2, column=2)
slider_mk = Scale(frame_buttonconfig, from_=100, to=0)
slider_mk.grid(row=2,column=3)
label_hk = Label(frame_buttonconfig, text="HK").grid(row=2, column=4)
slider_hk = Scale(frame_buttonconfig, from_=100, to=0)
slider_hk.grid(row=2,column=5)
label_shk = Label(frame_buttonconfig, text="SHK").grid(row=2, column=6)
slider_shk = Scale(frame_buttonconfig, from_=100, to=0)
slider_shk.grid(row=2,column=7)

label_up = Label(frame_buttonconfig, text="UP").grid(row=3, column=0)
slider_up = Scale(frame_buttonconfig, from_=100, to=0)
slider_up.grid(row=3,column=1)
label_down = Label(frame_buttonconfig, text="DOWN").grid(row=3, column=2)
slider_down = Scale(frame_buttonconfig, from_=100, to=0)
slider_down.grid(row=3,column=3)
label_left = Label(frame_buttonconfig, text="LEFT").grid(row=3, column=4)
slider_left = Scale(frame_buttonconfig, from_=100, to=0)
slider_left.grid(row=3,column=5)
label_right = Label(frame_buttonconfig, text = "RIGHT").grid(row=3, column=6)
slider_right = Scale(frame_buttonconfig, from_=100, to=0)
slider_right.grid(row=3,column=7)

label_start = Label(frame_buttonconfig, text="START").grid(row=4, column=0)
slider_start = Scale(frame_buttonconfig, from_=100, to=0)
slider_start.grid(row=4,column=1)
label_select = Label(frame_buttonconfig, text = "SELECT").grid(row=4, column=2)
slider_select = Scale(frame_buttonconfig, from_=100, to=0)
slider_select.grid(row=4,column=3)
label_turbo = Label(frame_buttonconfig, text="TURBO").grid(row=4, column=4)
slider_turbo = Scale(frame_buttonconfig, from_=100, to=0)
slider_turbo.grid(row=4,column=5)
label_home = Label(frame_buttonconfig, text="HOME").grid(row=4, column=6)
slider_home = Scale(frame_buttonconfig, from_=100, to=0)
slider_home.grid(row=4,column=7)



def get_button_threshold(serial_port, addr):
    writestr = 'GETTRIG;' + str(addr) + '\n'
    serial_port.write(writestr.encode())
    sleep(0.05)
    val = serial_port.readline()
    print(val)
    return float(val)
def get_all_thresholds(serial_port):
    writestr = 'GETALLTRIG;\n'
    serial_port.write(writestr.encode())
    sleep(0.05)
    val = serial_port.readline()
    val = str(val)[2::].split(';')
    val[15] = val[15][:-6]
    return val
def get_maxvals(serial_port):
    writestr = 'GETALLVAL;' + '\n'
    serial_port.write(writestr.encode())
    sleep(0.05)
    val = serial_port.readline()
    val = str(val)[2::].split(';')
    val[15] = val[15][:-6]
    return val


def initialize_entries():
    global maxvals, serial_port, progressbar_reading, slider_lp, slider_mp, slider_hp, slider_shp, slider_lk, slider_mk, slider_hk, slider_shk, slider_up, slider_down, slider_left, slider_right, slider_start, slider_select, slider_home, slider_turbo
    
    maxvals = get_maxvals(serial_port)
    vals = get_all_thresholds(serial_port)

    slider_lp.set(int(float(vals[0])/float(maxvals[0])*100))
    progressbar_reading.step(float(1)/16*100)
    slider_mp.set(int(float(vals[1])/float(maxvals[1])*100))
    progressbar_reading.step(float(1)/16*100)
    slider_hp.set(int(float(vals[2])/float(maxvals[2])*100))
    progressbar_reading.step(float(1)/16*100)
    slider_shp.set(int(float(vals[3])/float(maxvals[3])*100))
    
    progressbar_reading.step(float(1)/16*100)
    slider_lk.set(int(float(vals[4])/float(maxvals[4])*100))
    progressbar_reading.step(float(1)/16*100)
    slider_mk.set(int(float(vals[5])/float(maxvals[5])*100))
    progressbar_reading.step(float(1)/16*100)
    slider_hk.set(int(float(vals[6])/float(maxvals[6])*100))
    progressbar_reading.step(float(1)/16*100)
    slider_shk.set(int(float(vals[7])/float(maxvals[7])*100))

    progressbar_reading.step(float(1)/16*100)
    slider_left.set(int(float(vals[8])/float(maxvals[8])*100))
    progressbar_reading.step(float(1)/16*100)
    slider_right.set(int(float(vals[10])/float(maxvals[10])*100))
    progressbar_reading.step(float(1)/16*100)
    slider_up.set(int(float(vals[11])/float(maxvals[11])*100))
    progressbar_reading.step(float(1)/16*100)
    slider_down.set(int(float(vals[9])/float(maxvals[9])*100))

    progressbar_reading.step(float(1)/16*100)
    slider_start.set(int(float(vals[13])/float(maxvals[13])*100))
    progressbar_reading.step(float(1)/16*100)
    slider_select.set(int(float(vals[12])/float(maxvals[12])*100))
    progressbar_reading.step(float(1)/16*100)
    slider_home.set(int(float(vals[14])/float(maxvals[14])*100))
    progressbar_reading.step(float(1)/16*100)
    slider_turbo.set(int(float(vals[15])/float(maxvals[15])*100))
    progressbar_reading.step(float(1)/16*100)

    frame_buttonconfig.grid(row=0, column=0)
    frame_buttonconfig.tkraise()
    frame_connect.destroy()
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

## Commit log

2025-01-27 Added first pass of PCB for collecting initial components for the MCU.
    [CustomKeyboard.step, CustomKeypad.csv, KeyHolder1.obj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]
2025-01-30 Updated board with the right hall effect analog sensor and some ADCs. Considering reducing the MCU.
    [MainBoard.kicad_sch, buttons_hall.kicad_sch]
2025-01-31 Worked on schematic, added USB-C, worked on pcb
    [MainBoard.kicad_pcb, MainBoard.kicad_sch, USB4105-GF-A.step]
2025-02-04 Updated PCB and schematic with the Gateron footprint, added dummy Brooks footprint
    [MainBoard.kicad_pcb, MainBoard.kicad_sch, buttons_hall.kicad_sch]
2025-02-10 Fallback Pico GP2040-CE added
    [MainBoard.kicad_pcb, MainBoard.kicad_sch, MainBoard_RP2040.kicad_pcb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]
2025-02-10 Removed other controller boards from RP2040
    [MainBoard_RP2040.kicad_pcb]
2025-02-10 Added Gitignore
    [CustomKeyboard.step, CustomKeypad.csv, KeyHolder1.obj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]
2025-03-02 Confirmed working, moving towards PCB v1.1
    [MainBoard_RP2040-B_Cu.gbr, MainBoard_RP2040-B_Mask.gbr, MainBoard_RP2040-B_Paste.gbr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]
2025-04-05 Added the additional components to support the ADCs
    [MainBoard_RP2040.kicad_pcb, buttons_hall.kicad_sch]
2025-04-05 Working on layout of PCB to include the other components....
    [MainBoard_RP2040.kicad_pcb]
2025-04-08 PCB Updated to include the ADC improved components
    [MainBoard_RP2040.kicad_pcb, buttons_hall.kicad_sch]
2025-05-06 Added Gen5X and P5Mini versions. Updated the firmware to support new get all threshold and get all current level commands. Updated the user software to use draggable bars that scale t100% for highest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
    [MainBoard_BrooksGen5XMini-B_Cu.gbr, MainBoard_BrooksGen5XMini-B_Mask.gbr, MainBoard_BrooksGen5XMini-B_Paste.gbr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]
2025-05-06 Added protective diodes to RP2040 Board
    [MainBoard_RP2040.kicad_pcb, MainBoard_RP2040.kicad_sch]
